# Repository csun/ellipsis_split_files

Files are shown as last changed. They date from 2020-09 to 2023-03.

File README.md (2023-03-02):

KiCad files for the pcb in the `pcb/` directory

dxf files for the plates in the `plates/` directory. This includes files for the templates used to cut out the wrist rests.

# V2 Construction Notes
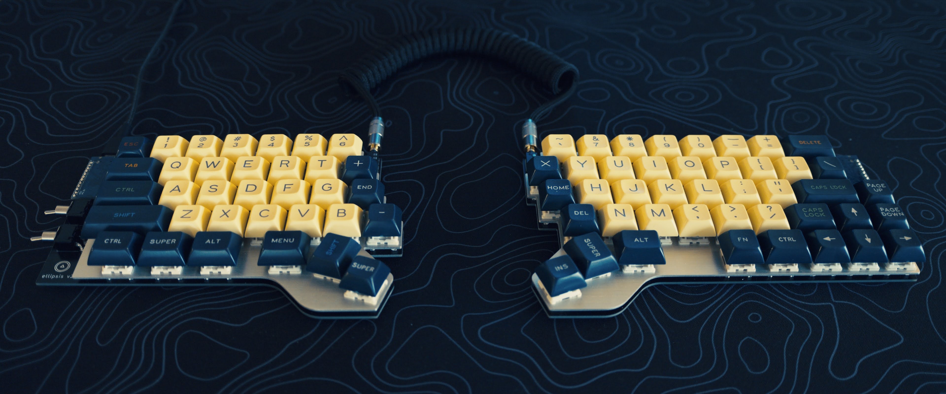
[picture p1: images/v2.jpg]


The board is laid out for [this specific aliexpress promicro clone](https://www.aliexpress.us/item/2251801162485383.html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). You can probably use a standard promicro, but the USB port will not be flush with the edge of the board.

The toggle switch used is the [E-Switch 100SP1T2B4M6QE](https://www.digikey.com/en/products/detail/e-switch/100SP1T2B4M6QE/378831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). TBH I'd buy a clone of this off aliexpress too and save yourself a bunch of money.

Firmware source can be found [here](https://github.com/csun/qmk_firmware/tree/ellipsis_split_v2) on the `ellipsis_split_v2` branch.

# V1 Construction Notes


Most of the components needed for assembly should be properly labelled in the pcb files. The screen used is [this adafruit one](https://www.adafruit.com/product/931) based on the SSD1306 driver chip.

I cut wrist rests from wood using the router template included in the plates directory.

You'll also need M2 standoffs of various lengths to separate the two plates enough to fit the PCB. I think around 12mm is the minimum allowable height.

Firmware source uses QMK and can be found [here](https://github.com/csun/ellipsis_split_firmware)

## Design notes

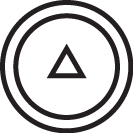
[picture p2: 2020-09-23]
pcb/v2/graphics/emblem_v3.png

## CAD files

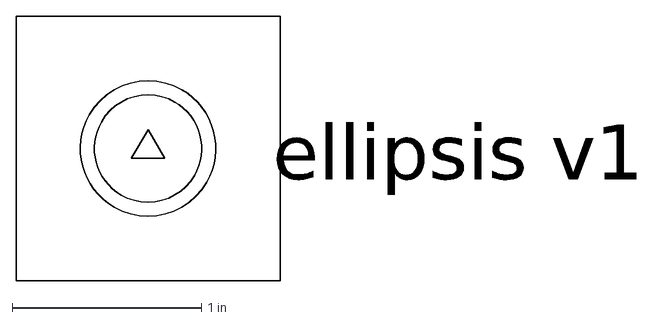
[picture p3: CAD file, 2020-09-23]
pcb/v2/graphics/ellipsis_pcb_logo.dxf
ellipsis v1

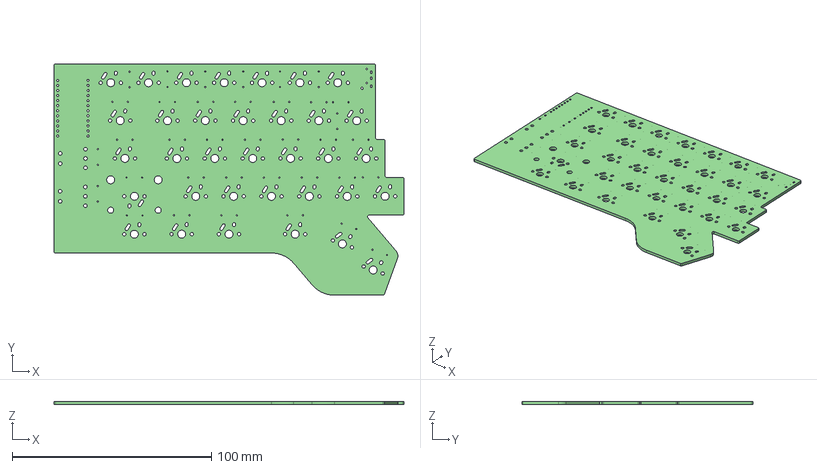
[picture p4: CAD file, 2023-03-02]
pcb/v2/left.step
175.7 x 116.2 x 1.60 mm

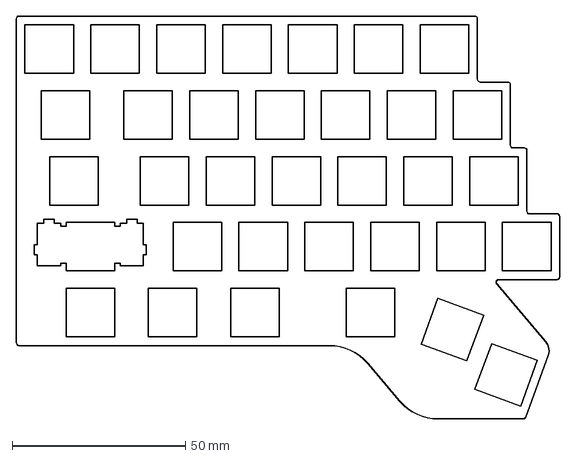
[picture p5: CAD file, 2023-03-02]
plates/v2/l_plate_FINAL.dxf
156.7 x 116.2 mm

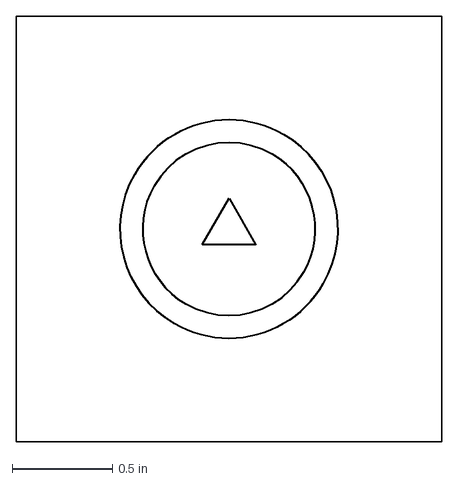
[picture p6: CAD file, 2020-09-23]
pcb/v2/graphics/emblem_v3.dxf
2.12 x 2.12 in

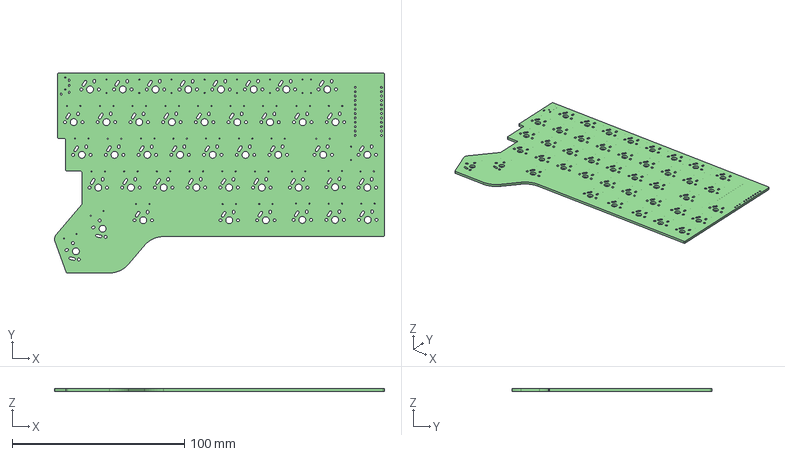
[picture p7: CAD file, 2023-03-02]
pcb/v2/right.step
191.7 x 116.2 x 1.60 mm

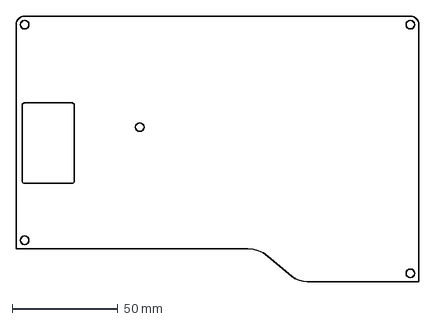
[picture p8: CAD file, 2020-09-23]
pcb/v2/l_edge_cut.dxf
190.5 x 125.7 mm

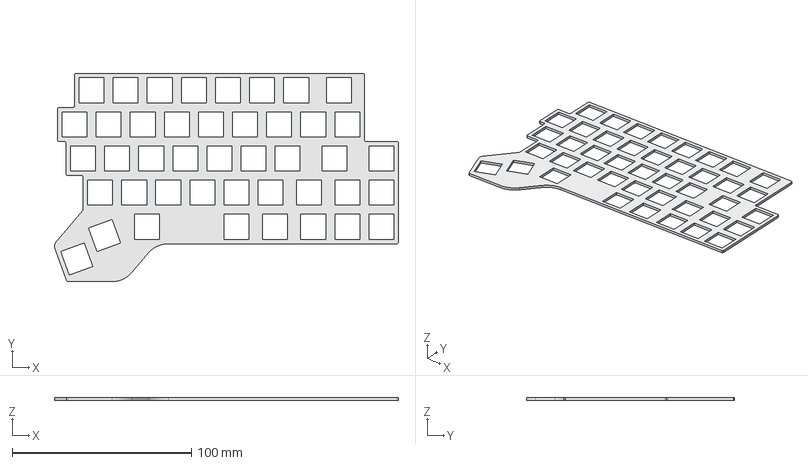
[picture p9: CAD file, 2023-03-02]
plates/v2/r_plate.FCStd
191.7 x 116.2 x 1.60 mm

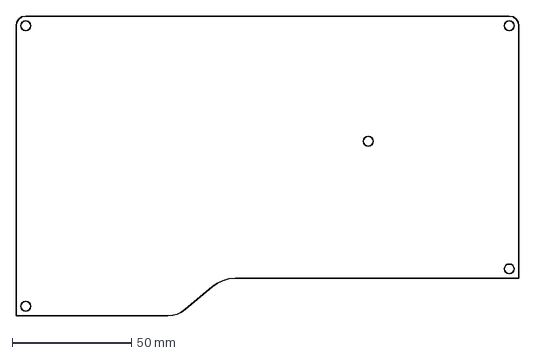
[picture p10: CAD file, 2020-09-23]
pcb/v2/r_edge_cut.dxf
210.9 x 125.7 mm

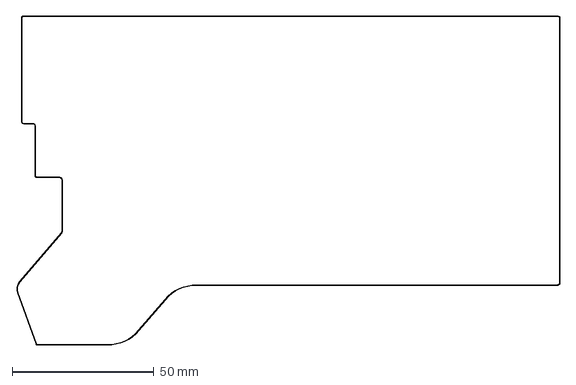
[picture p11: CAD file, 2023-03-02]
plates/v2/r_pcb_cut-sketch.dxf
191.9 x 116.2 mm

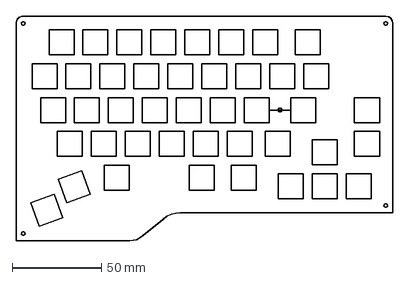
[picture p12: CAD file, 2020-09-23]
pcb/v2/r_plate.dxf
210.9 x 125.7 mm

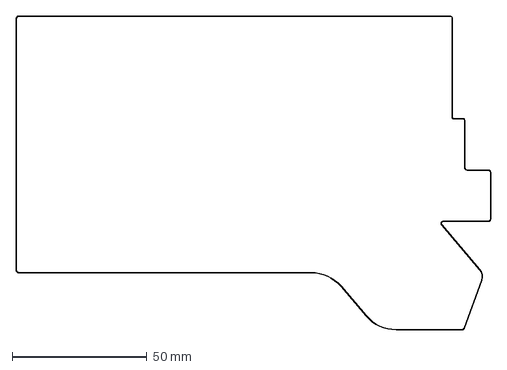
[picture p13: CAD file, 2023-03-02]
plates/v2/l_pcb_cut-sketch.dxf
175.7 x 116.2 mm

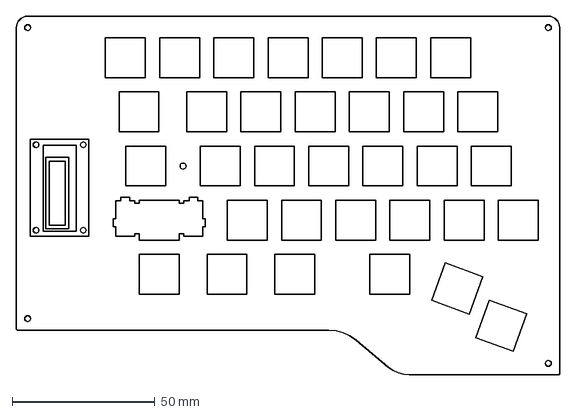
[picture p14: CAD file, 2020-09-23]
pcb/v2/l_plate.dxf
190.5 x 125.7 mm

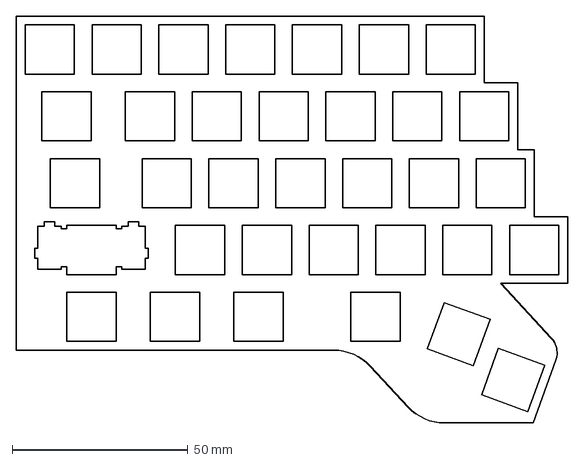
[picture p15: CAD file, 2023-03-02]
plates/v2/l_plate-sketch.dxf
156.7 x 115.7 mm

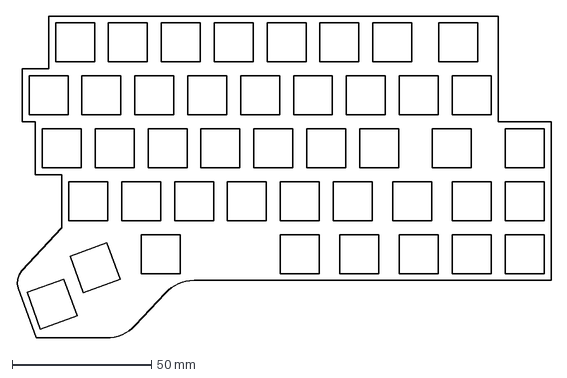
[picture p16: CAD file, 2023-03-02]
plates/v2/r_plate-sketch.dxf
192.2 x 115.7 mm

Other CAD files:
plates/v2/r_pcb_cut.FCStd
plates/v2/l_plate.FCStd
plates/v2/r_plate_FINAL.dxf
plates/v2/l_pcb_cut.FCStd
plates/v1/l_bottom_plate.dxf
plates/v1/l_rest_template.dxf
plates/v1/l_top_plate.dxf
plates/v1/r_bottom_plate.dxf
plates/v1/r_rest_template.dxf
plates/v1/r_top_plate.dxf

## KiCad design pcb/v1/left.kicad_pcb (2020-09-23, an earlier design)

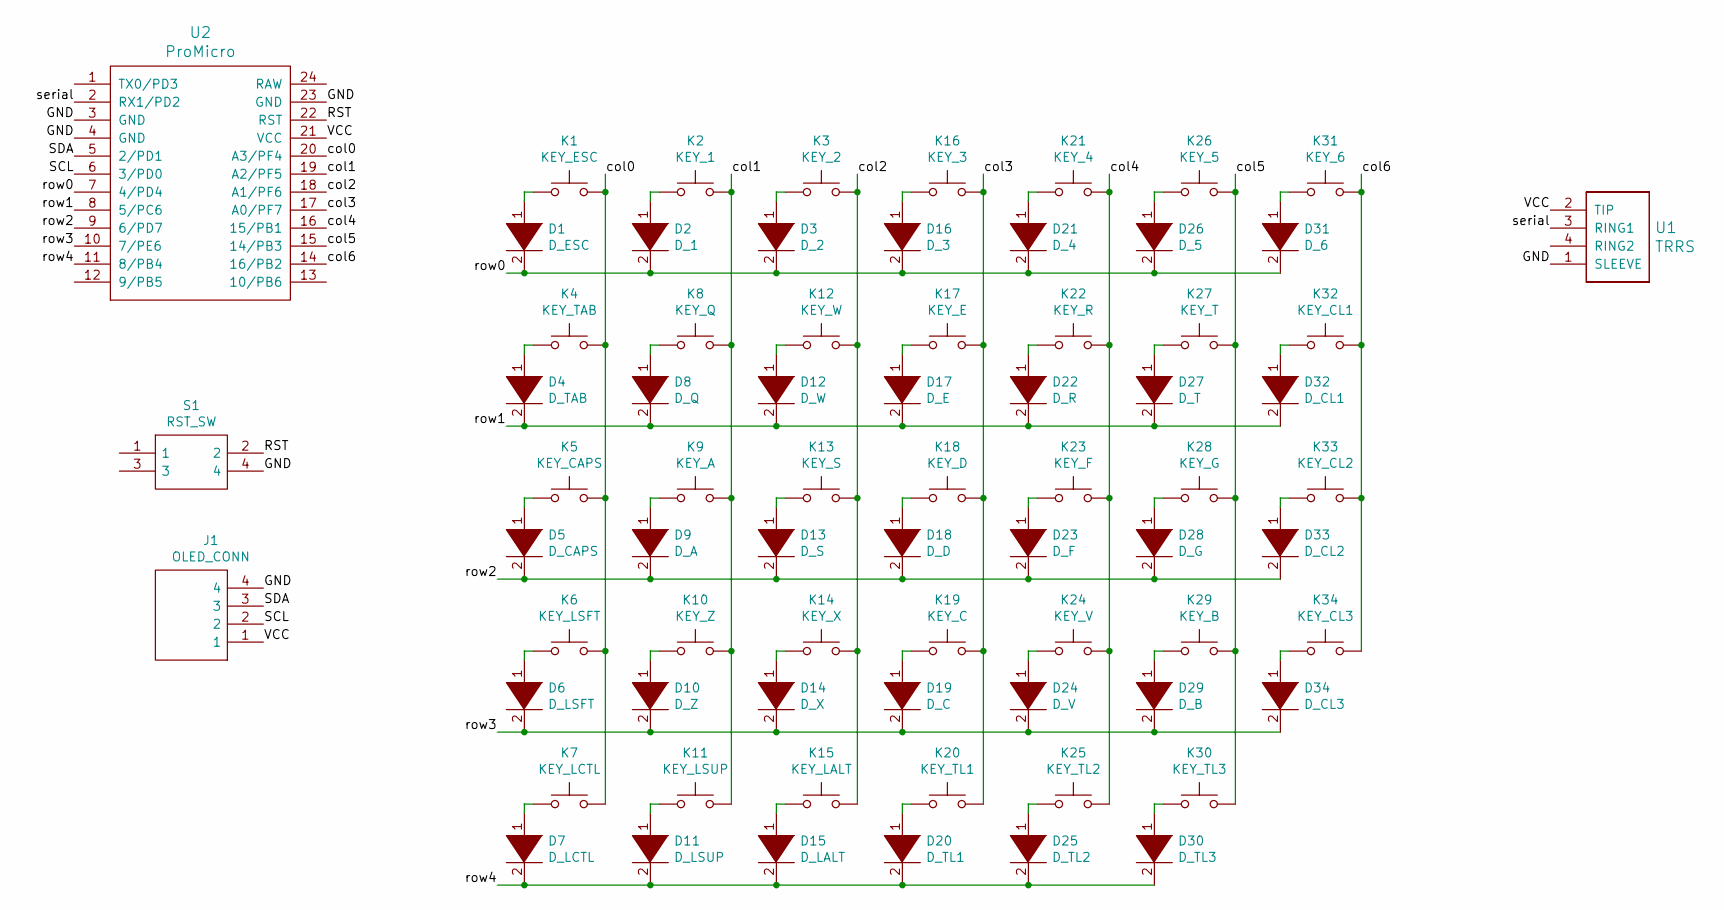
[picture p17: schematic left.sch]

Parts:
D1: D_ESC; D_SOD123_axial
D2: D_1; D_SOD123_axial
D3: D_2; D_SOD123_axial
D4: D_TAB; D_SOD123_axial
D5: D_CAPS; D_SOD123_axial
D6: D_LSFT; D_SOD123_axial
D7: D_LCTL; D_SOD123_axial
D8: D_Q; D_SOD123_axial
D9: D_A; D_SOD123_axial
D10: D_Z; D_SOD123_axial
D11: D_LSUP; D_SOD123_axial
D12: D_W; D_SOD123_axial
D13: D_S; D_SOD123_axial
D14: D_X; D_SOD123_axial
D15: D_LALT; D_SOD123_axial
D16: D_3; D_SOD123_axial
D17: D_E; D_SOD123_axial
D18: D_D; D_SOD123_axial
D19: D_C; D_SOD123_axial
D20: D_TL1; D_SOD123_axial
D21: D_4; D_SOD123_axial
D22: D_R; D_SOD123_axial
D23: D_F; D_SOD123_axial
D24: D_V; D_SOD123_axial
D25: D_TL2; D_SOD123_axial
D26: D_5; D_SOD123_axial
D27: D_T; D_SOD123_axial
D28: D_G; D_SOD123_axial
D29: D_B; D_SOD123_axial
D30: D_TL3; D_SOD123_axial
D31: D_6; D_SOD123_axial
D32: D_CL1; D_SOD123_axial
D33: D_CL2; D_SOD123_axial
D34: D_CL3; D_SOD123_axial
J1: OLED_CONN; SHDR4W60P0X250_1X4_1240X1150X670P; Mouser Part Number 538-53426-0410
K1: KEY_ESC; Mx_Alps_100
K2: KEY_1; Mx_Alps_100
K3: KEY_2; Mx_Alps_100
K4: KEY_TAB; Mx_Alps_150
K5: KEY_CAPS; Mx_Alps_175
K6: KEY_LSFT; Mx_Alps_225
K7: KEY_LCTL; Mx_Alps_125
K8: KEY_Q; Mx_Alps_100
K9: KEY_A; Mx_Alps_100
K10: KEY_Z; Mx_Alps_100
K11: KEY_LSUP; Mx_Alps_125
K12: KEY_W; Mx_Alps_100
K13: KEY_S; Mx_Alps_100
K14: KEY_X; Mx_Alps_100
K15: KEY_LALT; Mx_Alps_125
K16: KEY_3; Mx_Alps_100
K17: KEY_E; Mx_Alps_100
K18: KEY_D; Mx_Alps_100
K19: KEY_C; Mx_Alps_100
K20: KEY_TL1; Mx_Alps_125
K21: KEY_4; Mx_Alps_100
K22: KEY_R; Mx_Alps_100
K23: KEY_F; Mx_Alps_100
K24: KEY_V; Mx_Alps_100
K25: KEY_TL2; Mx_Alps_125
K26: KEY_5; Mx_Alps_100
K27: KEY_T; Mx_Alps_100
K28: KEY_G; Mx_Alps_100
K29: KEY_B; Mx_Alps_100
K30: KEY_TL3; Mx_Alps_125
K31: KEY_6; Mx_Alps_100
K32: KEY_CL1; Mx_Alps_100
K33: KEY_CL2; Mx_Alps_100
K34: KEY_CL3; Mx_Alps_100
S1: RST_SW; LL3301NF065QG; Mouser Part Number 612-LL3301NF065QG
U1: TRRS; TRRS-PJ-320A
U2: ProMicro; ArduinoProMicro

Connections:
/GND: J1.4, S1.4, U1.1 (SLEEVE), U2.3 (GND), U2.4 (GND), U2.23 (GND)
/RST: S1.2, U2.22 (RST)
/SCL: J1.2, U2.6 (3/PD0)
/SDA: J1.3, U2.5 (2/PD1)
/VCC: J1.1, U1.2 (TIP), U2.21 (VCC)
/col0: K1.2, K4.2, K5.2, K6.2, K7.2, U2.20 (A3/PF4)
/col1: K2.2, K8.2, K9.2, K10.2, K11.2, U2.19 (A2/PF5)
/col2: K3.2, K12.2, K13.2, K14.2, K15.2, U2.18 (A1/PF6)
/col3: K16.2, K17.2, K18.2, K19.2, K20.2, U2.17 (A0/PF7)
/col4: K21.2, K22.2, K23.2, K24.2, K25.2, U2.16 (15/PB1)
/col5: K26.2, K27.2, K28.2, K29.2, K30.2, U2.15 (14/PB3)
/col6: K31.2, K32.2, K33.2, K34.2, U2.14 (16/PB2)
/row0: D1.2 (A), D2.2 (A), D3.2 (A), D16.2 (A), D21.2 (A), D26.2 (A), D31.2 (A), U2.7 (4/PD4)
/row1: D4.2 (A), D8.2 (A), D12.2 (A), D17.2 (A), D22.2 (A), D27.2 (A), D32.2 (A), U2.8 (5/PC6)
/row2: D5.2 (A), D9.2 (A), D13.2 (A), D18.2 (A), D23.2 (A), D28.2 (A), D33.2 (A), U2.9 (6/PD7)
/row3: D6.2 (A), D10.2 (A), D14.2 (A), D19.2 (A), D24.2 (A), D29.2 (A), D34.2 (A), U2.10 (7/PE6)
/row4: D7.2 (A), D11.2 (A), D15.2 (A), D20.2 (A), D25.2 (A), D30.2 (A), U2.11 (8/PB4)
/serial: U1.3 (RING1), U2.2 (RX1/PD2)
unnamed: D1.1 (K), K1.1
unnamed: D2.1 (K), K2.1
unnamed: D3.1 (K), K3.1
unnamed: D4.1 (K), K4.1
unnamed: D5.1 (K), K5.1
unnamed: D6.1 (K), K6.1
unnamed: D7.1 (K), K7.1
unnamed: D8.1 (K), K8.1
unnamed: D9.1 (K), K9.1
unnamed: D10.1 (K), K10.1
unnamed: D11.1 (K), K11.1
unnamed: D12.1 (K), K12.1
unnamed: D13.1 (K), K13.1
unnamed: D14.1 (K), K14.1
unnamed: D15.1 (K), K15.1
unnamed: D16.1 (K), K16.1
unnamed: D17.1 (K), K17.1
unnamed: D18.1 (K), K18.1
unnamed: D19.1 (K), K19.1
unnamed: D20.1 (K), K20.1
unnamed: D21.1 (K), K21.1
unnamed: D22.1 (K), K22.1
unnamed: D23.1 (K), K23.1
unnamed: D24.1 (K), K24.1
unnamed: D25.1 (K), K25.1
unnamed: D26.1 (K), K26.1
unnamed: D27.1 (K), K27.1
unnamed: D28.1 (K), K28.1
unnamed: D29.1 (K), K29.1
unnamed: D30.1 (K), K30.1
unnamed: D31.1 (K), K31.1
unnamed: D32.1 (K), K32.1
unnamed: D33.1 (K), K33.1
unnamed: D34.1 (K), K34.1

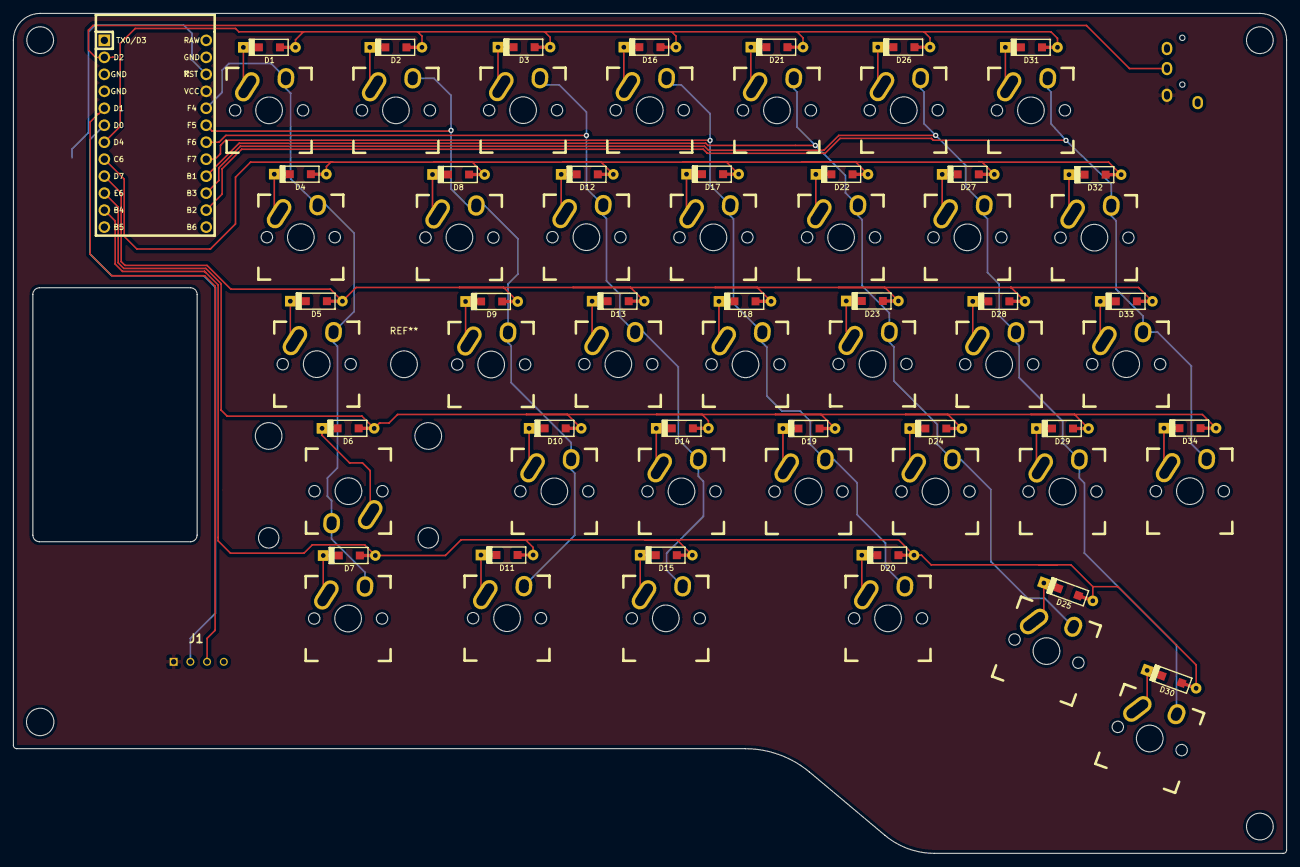
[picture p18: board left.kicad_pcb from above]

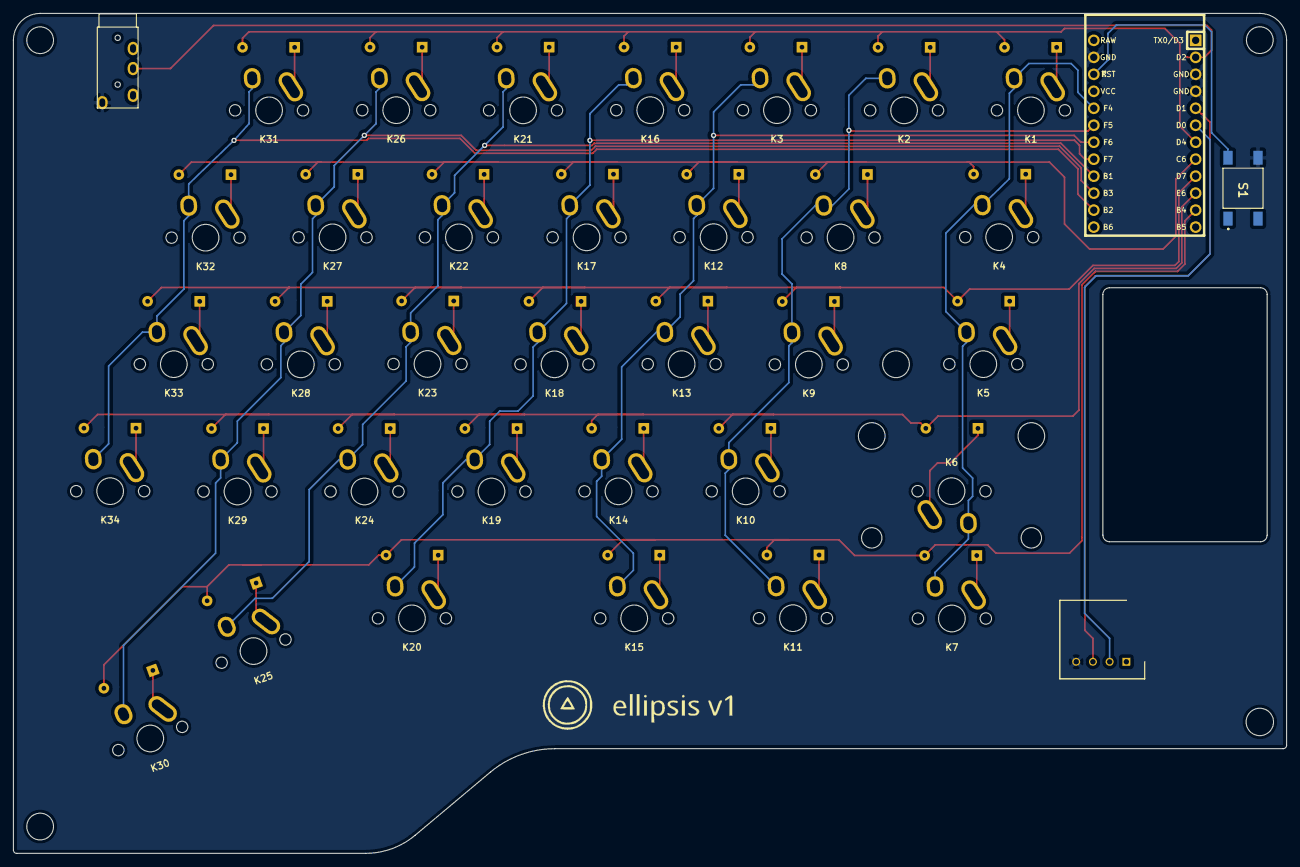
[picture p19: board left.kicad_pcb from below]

Board: 2 copper layers, 190.5 x 125.7 mm, 76 parts (3 on the bottom side), 52 nets.

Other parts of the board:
 : MountingHole_4mm
 #2,  #3,  #4: MountingHole_4mm

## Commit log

2022-12-21 start work on v2
    [l_plate-sketch.dxf, l_plate.FCStd]
2022-12-24 Starting to wire left side
    [l_pcb_cut-sketch.dxf, l_pcb_cut.FCStd, l_plate-sketch.dxf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]
2022-12-24 Left pcb should be done
    [left-B_Cu.gbl, left-B_Cu.gbr, left-B_Mask.gbr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]
2022-12-24 Starting on right pcb
    [l_pcb_cut.FCStd, l_plate.FCStd, left.kicad_pcb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]
2022-12-26 Trying to add some fillets but something is messed up
    [l_pcb_cut.FCStd, l_plate.FCStd, l_plate_FINAL.dxf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]
2022-12-27 This is the version that I sent to manufacturers
    [l_pcb_cut-sketch.dxf, l_pcb_cut.FCStd, l_plate.FCStd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]
2022-12-27 Reorganized so that pcb has v1 and v2 folders too
    [ellipsis_pcb_logo.dxf, emblem_v3.dxf, l_edge_cut.dxf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]
